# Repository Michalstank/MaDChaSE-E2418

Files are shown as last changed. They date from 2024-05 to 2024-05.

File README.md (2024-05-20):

# Massive Distributed Channel Sounding Equipment 

Dette er repositoriet for bacheloroppgaven "MaDChaSE", i forbindelse med studieretningen elektronikk og sensorsystemer ved [NTNU](https://www.ntnu.no/). Med støtte fra [Nordic Semiconductor](https://www.nordicsemi.com/), ble prosjektet gjennomført for å utvikle et konseptbevis for et system som muliggjør massiv distribuering av noder i stand til å gjennomføre [kanalmåling](https://www.bluetooth.com/specifications/specs/channel-sounding-cr-pr/). Oppgaven ble avgrenset til håndteringen av hundrevis av noder på et nettverk. Dette inkluderer arbeid som: 

- Prototyping av noder.
- Distribuering av fastvare. 
- Verktøy for oppkobling av nye noder til et WiFi-nettverk.
- Kanalmålingsorkestrering og datainnsamling. 

Alle relevante filer inkludert dette databladet finnes under følgende link: https://github.com/Michalstank/MaDChaSE-E2418

## Innholdsfortegnelse
1. [Systemarkitektur](#systemarkitektur)
2. [Requirements](#Requirements)
   1. [Hardware](#hardware)
   2. [Software](#software)
   3. [nRF Libraries](#nrf-libraries) 
4. [Guide for oppsett](#guide-for-oppsett)
    1. [Hardware Oppsett](#Hardware-Oppsett)
    3. [Server Oppsett](#Server-Oppsett)
    4. [Distribusjon av fastvare](#distribusjon-av-fastvare)
    5. [RPI Oppsett](#RPI-Oppsett)
5. [Bash Script](#bash-script)
    1. [Flagg Oversikt](#flagg-oversikt)
    2. [Flagg Kode](#flagg-kode)
  
# Systemarkitektur
Det utviklede systemet baserer seg på noder i form av [nRF52833 Dk.]( https://www.nordicsemi.com/Products/Development-hardware/nRF52833-DK) og [RPI 3B+](https://www.raspberrypi.com/products/raspberry-pi-3-model-b-plus/). nRF-enheten gjennomfører kanalmålinger, mens RPI 3B+ står for nettverkskommunikasjon og distribuerer fastvare nødvendig for målingene. En server brukes som mellomleddet mellom nodene og brukergrensesnittet. Serveren kommuniserer med nodene over et WiFi-nettverk og står for kanalmålingsorkestrering og samhandling. Brukergrensesnittet er i form av en nettside. 


# Requirements
## Hardware 
- En Router / Access Point med Wi-Fi
- nRF52833 Dk.
- Raspberry Pi 3B+ (Eller tilsvarende modell som støtter Rasbian v11.9)
- Micro SD kort
- Power Supply for RPI 
- USB-A til Micro-USB-B kabel

## Software 
- Minst versjon av NodeJS v18.13.0.
- Node pakkene: socketio, express.
- Mulighet for å sjekke IP av enheter koblet til Routeren / Access Point (Eksempelvis logg deg på ruteren du skal bruke for å undersøke dette).
## nRF Libraries
- <zephyr/kernel.h>
- <zephyr/gpio.h>
- <zephyr/uart.h>
- [libnrf_dm.a](https://github.com/nrfconnect/sdk-nrfxlib/blob/main/nrf_dm/lib/nrf52833/hard-float/libnrf_dm.a)

# Guide for oppsett
## Hardware oppsett
RPI 3B+ og nRF52833 Dk. som utgjør nodene, kommuniserer med hverandre ved hjelp av UART-protokollen. For å muliggjøre kommunikasjonen, kobl nRF-en til en av USB-A portene på RPI. For å forsyne noden med strøm kobl RPI til strømforsyning. Dette kreves ikke enda, det gjennomføres underveis RPI oppsettet.

Det ble også utviklet en innkapsling til nodene som kan 3D-printes. De tilhørende filene finnes [her.](https://github.com/Michalstank/MaDChaSE-E2418/tree/48b5f4ba134b89f2b8a7d6ff9e974852505d02e9/Extras)


## Server oppsett

Denne delen har som formål å presentere de nødvendige stegene for å sette opp serveren. 

1. Last ned [Server Files](https://github.com/Michalstank/MaDChaSE-E2418/tree/main/SVR).
2. Utpakk filene og bestem hvilken algoritme du ønsker å bruke (list eller rng.).
3. Start 'Node.js Command Prompt'
4. Start serveren ved å skrive inn følgende kommando:
```bash
node server_file_name.js
```
5. Om det forekommer en feil, dobbelsjekk at alle filene er i samme mappe.
6. For å logge på brukergrensesnittet, finn først IP-en til datamaskinen der serveren skal 'hostes' og legg til dens port på følgende form: IP:PORT. For å nå brukergrensesnittet skriv deretter den sammensatte IP-en og porten inn i nettleseren.
```bash
192.168.10.187:3000 or localhost:3000
```
7. For at nodene skal være i stand til å koble seg opp til serveren din, endr client.py filen. Definer IP'en du tidligere fant på linje 119:
```python
sio.connect('http://IP:PORT', retry = True); example: sio.connect('http://192.168.2.12:3000', retry = True) 
```

## Distribusjon av fastvare

Nodene i prosjektet henter programvaren sin fra et gitt [Github Repo.](https://github.com/Michalstank/MaDChaSE-E2418-Fastvare) Om du har lyst å endre hvilket repo fastvaren lastes ned fra, endr linken i flagg ['-d'](#flagg--d-kode) i bash scriptet til ønsket repo.<br/> HUSK: linken som erstattes skal være til et 'raw' format av filen på github. Dette gir deg muligheten til å teste ut din egen fastvare på nodene. 

## RPI Oppsett

Denne delen forklarer trinnvis hvordan nodene skal settes opp og programmeres. For hver node i systemet gjennomfør følgende oppstartsprosedyre:

1. Last ned filene: [Bash Script](https://github.com/Michalstank/MaDChaSE-E2418/blob/main/RPI/node_system.sh), [Raspberry Pi Imager](https://downloads.raspberrypi.org/imager/imager_latest.exe) og [RPI Image](https://downloads.raspberrypi.com/raspios_oldstable_full_armhf/images/raspios_oldstable_full_armhf-2024-03-12/2024-03-12-raspios-bullseye-armhf-full.img.xz).
3. Flash RPI SD kortet ved bruk av Raspberry Pi Imager, bildet nedenfor viser anbefalt konfigurasjon. (Huske å legge til Wi-Fi login og passord til nettverket du ønsker at nodene skal kobles på):<br />
   

5. Legg inn SD-kortet i RPI og kobl enheten til strøm. Deretter logg på Router / Access Point for å hente dens IP-adresse.
6. Send over bash script-filen ved bruk av:
```bash
scp PATH_TO_BASH_SCRIPT rpi_navn@rpi_ip:/home/rpi_navn/
```
6. Kobl deg opp til noden ved hjelp av SSH-protokollen: <br /> Hint: Dette steget kan unngås dersom du kobler opp din RPI til en skjerm og tastatur. Etter oppkoblingen åpn opp terminalen og følg steg 7.
```bash
shh rpi_navn@rpi_ip 
```
7. Gjør Bash scriptet til en executable:
```bash
chmod u+x bash_script_navn.sh
```
8. Nå er det mulig å kjøre Bash scriptet dersom man er i samme directory som den:
```bash
./bash_script_navn.sh
```
9. Bash scriptet kan nå også konfigureres til å kjøre ved systemstart. Dette gjøres ved å legge dens 'path' til rc.local filen:
```bash
sudo nano /etc/rc.local
```
10. Dersom du har fulgt stegene skal oppsettet ligne på det nedenfor:
```bash
#Kommentar og default kode over...
./home/rpi_navn/bash_script_navn.sh
```

# Bash Script
Nodenes fastvare oppdateres ved hjelp av et Bash script. Det anvendes for å laste ned bibliotekene, filene og verktøyene som brukes på RPI-en.
## Flagg Oversikt

| Flag | Funksjon |
|---|---|
|`-p`  | Installerer nødvendige Python-bibliotek systemet benytter. |
|`-d`  | Laster ned de nye filene for noden: Client.py og Zephyr.hex (Fastvare for nFR). |
|`-f`  | Installer JLink på RPI og lager et eget directory for den. |
|`-j`  | Installerer fastvare til nRF-en ved hejlp av HEX-filer via. JLink. |
|`-r`  | Sletter gammelt directory laget for JLink. |
|`-s`  | Starter klient-delen etter prosessering av tidligere flagg. |

## Flagg Kode
### Flagg '-p' Kode
```bash
	p) 
		#Update RPI system
		sudo apt-get -y update

		sudo apt-get -y upgrade

		#Install needed python packages
		sudo pip install python-socketio

		sudo pip install "python-socketio[client]"

		sudo pip install pyserial
	;;
```
### Flagg '-d' Kode
```bash
#Download new client and hex file
	d)
		#Remove Old Files
		sudo rm client.py
		sudo rm zephyr.hex

		#Download python client code
		wget --no-check-certificate "https://raw.githubusercontent.com/Michalstank/TEST-DOWNLOAD-REPO/main/client.py"

		#Download hexfile code
		wget --no-check-certificate "https://raw.githubusercontent.com/Michalstank/TEST-DOWNLOAD-REPO/main/zephyr.hex"
	;;
```
### Flagg '-f' Kode
```bash
#Flash Using JLink
	f)	
		#Download Expect and Install Expect, Needed For Flashing/Dealing with JLink
		sudo apt-get -y install expect

		#Move To JLink Directory
		cd JLINK_DATA

		#Start Expect and run JLink Flashing Process
		expect <<-EOF
			set timeout -1
			spawn sudo ./JLinkExe
			expect "J-Link>" 	{ send "connect\r" 	}
			expect "Device>"	{ send "nrf52833\r"	}
			expect "TIF>" 		{ send "S\r" 		}
			expect "Speed>"		{ send "\r" 		}
			expect "J-Link>"	{ send "loadfile /home/e2418/zephyr.hex\r"}
			expect "J-Link>"	{ send "r\r"		}
			expect "J-Link>"	{ send "g\r"		}
			expect "J-Link>"	{ send "exit\r"		}
		EOF

		#Return the the previous directory after done with flashing
		cd ..
	;;
```
### Flagg '-j' Kode
```bash
#Install JLink
	j) 
		#Remove Old JLink Folder
		sudo rm -r JLINK_DATA

		#Download JLink Package
		sudo wget --post-data 'accept_license_agreement=accepted&non_emb_ctr=confirmed&submit=Download+software' https://www.segger.com/downloads/jlink/JLink_Linux_arm.tgz

		#Create Unpack Directory
		sudo mkdir JLINK_DATA

		#Unpack JLink into Its New Directory
		sudo tar -xf JLink_Linux_arm.tgz -C ./JLINK_DATA --strip-components=1

		#Delete JLink Package
		sudo rm JLink_Linux_arm.tgz
	;;
```
### Flagg '-r' Kode
```bash
#Remove JLink folder post install
	r)
		sudo rm -r JLINK_DATA
	;;
```
### Flagg '-s' Kode
```bash
#Run the server
	s) 
		python client.py
	;;
```

# Anerkjennelser
- Vi vil rette en spesiell takk til vår eksterne veileder [Carsten Wulff](https://www.ntnu.no/ansatte/carstenw), for teknisk assistanse og verdifulle tilbakemeldinger underveis i prosjektgjennomføringen. Vi setter pris på [eksempelkoden](https://github.com/wulffern/nrfdmiq/tree/main) vi fikk mulighet til å ta i bruk.
- Vi vil også takke vår prosessveileder [Arne Midjo](https://www.ntnu.no/ansatte/arne.midjo) for råd og støtte gjennom hele prosjektet.

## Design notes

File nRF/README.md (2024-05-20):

# Innhold: 
Denne mappen inneholder main.c filen og de tilhørende bibliotekene for nRF52833 Dk. Dette inkluderer: 

- libnrf_dm.a = Nordic Semiconductor sitt bibliotek for Channel Sounding.
- main.c = Hovedkoden for nRF-enhetene.
- nrf_dm.h = Header fil for libnrf_dm.a biblioteket.
- uart_com.h = Bibliotek for UART kommunikasjon.
- zephyr.hex = Hovedfilen som skal lastes opp på nRF-enhetene.

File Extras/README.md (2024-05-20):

# Extras

Dette er en mappe som inneholder andre relevante ting for prosjektet. Dette inkluderer:
- Filene for 3D-printing av innkapslingen.
- Plotting av data
- Rå data fra de gjennomførte testene. 

I den endelige løsingen ble serveren satt opp for å behandle data på en måte som tilrettelegger for videre prosessering ved hjelp av python bibliotek som pandas. Under gruppens tester ble et alternativt format brukt, for å øke lesbarheten.

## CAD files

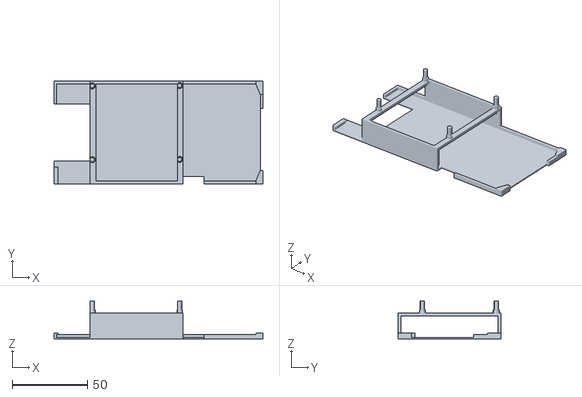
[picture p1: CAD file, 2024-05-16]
Extras/3Dprint/nrf_3d_mode_case.stl
138.7 x 68.1 x 25.0

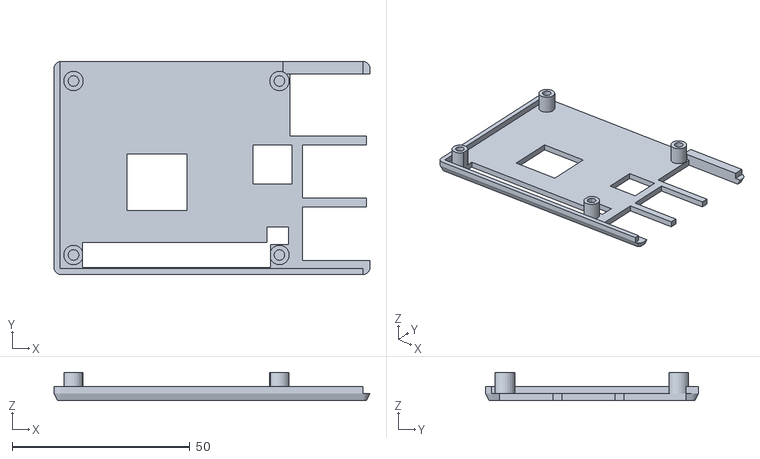
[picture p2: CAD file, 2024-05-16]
Extras/3Dprint/rpi_3d_model_case.stl
89.0 x 60.0 x 8.00

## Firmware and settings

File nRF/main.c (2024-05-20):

/*
	* USE EXTENSION "BETTER COMMENTS by Aaron Bond" FOR BETTER READABILITY
	
	Ref:

	Normal Comment
	//Crossed off Comment (if in multiline comment)
	!RED ERROR LIKE COMMENT
	TODO: TODO ITEM
	* BRIGH COMMENT
	? QUESTION COMMENT ?
*/

#include <zephyr/kernel.h>

#include <zephyr/drivers/gpio.h>
#include <zephyr/drivers/uart.h>

#include <string.h>
#include <stdlib.h>
#include <stdio.h>
#include <stdbool.h>

#include "nrf_dm.h"
#include "uart_com.h"

/*
	Struct used to keep data about the UART Configuration
*/
const struct uart_config uart_cnf = {
	.baudrate = 115200,
	.parity = UART_CFG_PARITY_NONE,
	.stop_bits = UART_CFG_STOP_BITS_1,
	.data_bits = UART_CFG_DATA_BITS_8,
	.flow_ctrl = UART_CFG_FLOW_CTRL_NONE
};

typedef enum {
    INITIATOR,
    REFLECTOR,
    NONE
} NODE_TYPE;

bool node_update_role = false;
bool run_meas = false;

NODE_TYPE node_mode = NONE;

void update_role();

int main(void)
{
	//Check If Ready
	if(!device_is_ready(uart_dev)){
		return 10;
	}

	//Check if Configuration Avaible on the Card
	int err = uart_configure(uart_dev, &uart_cnf);

	//If Error Code Match Return Error Code
	if(err == -ENOSYS){
		return -ENOSYS;
	}

	uart_init();

	// * Main Loop

	while(1){

		//Configures and enables the Recieve for UART
		uart_rx_enable(uart_dev, uart_data, sizeof(char)*uart_buffer_size,0);

		//If 4th character in the buffer is not the end of string execute processing of command
		if(uart_data[3] != '\0'){	
			node_update_role = true;	
			uart_rx_disable(uart_dev);
		}

		//Execute code to update role
		update_role();
		
		/*
			Code to execute when the system is set to Initiator Mode
		*/
		if(node_mode == INITIATOR && run_meas){
			
			uart_reset_raport();

			uint32_t nrf_timeout_us 		= 0.5e6;

			nrf_dm_status_t status = nrf_dm_proc_execute(nrf_timeout_us);

			float uart_dis 					= 0;
			uint32_t uart_dur 				= 0;
			uint8_t hopping_seq[NRF_DM_CHANNEL_MAP_LEN];


			/*
				If distance was measured successfully the system will calculate distances
				The distances will be calculated using both the simplified less accurate nrf_dm_calc
				as well as the high precission algorithm nrf_dm_high_precision_calc
			*/
			if(status == NRF_DM_STATUS_SUCCESS){

				nrf_dm_populate_report(&uart_dm_report);

				nrf_dm_calc(&uart_dm_report);

				uart_dur = nrf_dm_get_duration_us(&uart_dm_config);

				uart_dis = nrf_dm_high_precision_calc(&uart_dm_report);

				nrf_dm_get_hopping_sequence(&uart_dm_config, hopping_seq);
			} else {
				//If Distance Measurement failed set quality to 100
				uart_dm_report.quality = 100;
			}

			//Quality 100 = Failed measurement therefore the system will transmit anything but Quality = 100
			if(uart_dm_report.quality != 100){
				//Translate Measured Data to JSON format and transmit it over UART
				uart_nrf_dm_report_to_json(&uart_dm_report, uart_dis, uart_dur, hopping_seq);
			}

			run_meas = false;

		/*
			Code to execute when the node is set to reflector mode
			Primarly focuses on the configuration of the nrf into reflector mode
		*/
		} else if(node_mode == REFLECTOR && run_meas){

			nrf_dm_status_t status = nrf_dm_configure(&uart_dm_config);

			uint32_t dm_timeout = 1e6;

			status = nrf_dm_proc_execute(dm_timeout);

			run_meas = false;
		}
	}
	return 0;
}

/*
	@brief Code to execute once a command from rpi has been recieved. @brief
	@note Proccesses how to configure the nrf based on the recived command.
*/
void update_role(){
	if(node_update_role){

		nrf_dm_role_t current_role;

		//Read Content of USART Transmmited string and compare if it is one of recognised command
		if(        !strncmp(uart_data,"Init.",4)){
			//Set seed necesary for the distance measurement system
			uart_dm_config.rng_seed 	= 0x44ddaafa;

			//Change Mode of node to initiator and change the configuration of dm config
			node_mode = INITIATOR;

			//Update the distance measurement config
			uart_dm_config 				= NRF_DM_DEFAULT_CONFIG;
			uart_dm_config.role			= NRF_DM_ROLE_INITIATOR;

			current_role 				= NRF_DM_ROLE_INITIATOR;

			//Stop the measurement
			run_meas = false;

			//Check if configuration of dm lib was succesful
			nrf_dm_configure(&uart_dm_config);

		//Same functionality as first if case
		} else if (!strncmp(uart_data,"Refl.",4)){
			uart_dm_config.rng_seed 	= 0x44ddaafa;

			node_mode = REFLECTOR;

			uart_dm_config 				= NRF_DM_DEFAULT_CONFIG;
			uart_dm_config.role			= NRF_DM_ROLE_REFLECTOR;

			current_role 				= NRF_DM_ROLE_REFLECTOR;

			run_meas = false;

			nrf_dm_configure(&uart_dm_config);
		//Same functionality as first if case
		} else if (!strncmp(uart_data,"None.",4)){
			uart_dm_config.rng_seed 	= 0;

			node_mode = NONE;

			uart_dm_config 				= NRF_DM_DEFAULT_CONFIG;
			uart_dm_config.role			= NRF_DM_ROLE_NONE;

			current_role 				= NRF_DM_ROLE_NONE;

			nrf_dm_configure(&uart_dm_config);

			run_meas = false;
		
		//
		} else if (!strncmp(uart_data, "Meas.", 4)){
			run_meas = true;
			current_role = uart_dm_config.role;
			uart_put_string("CMeas Start.");
			//If the command does not match any of the predetermined print "Wrong Comamnd" back to the server
		}else {	
			uart_put_string("Cwrng_cmd.");
		}

		//Double check if the mode has updated successfully.
		//If correct print out confirmation to the server.
		if(uart_dm_config.role == current_role){
			uart_put_string("CConf.");
		} else {
			uart_put_string("Cwrng.");
		}

		node_update_role = false;

		//Reset Input String
		memset(uart_data, '\0' , sizeof(uart_data));
	}
}

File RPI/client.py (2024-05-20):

#Socket.io Library
import socketio

#Random ID Generation
import random

#Serial Communication Libraries
import serial
from time import sleep

#Terminal Access Library
import os

#Node Class Definition, going to hold all important information about the node
class Node:
	node_unique_id 	= 0
	node_network_id = 0
	node_mode 	= 0
	node_data	= 0
	node_max_rand	= 100_000_000

#Creates node_info, main variable used to keep track of node information
node_info = Node()

#Variable to keep track if data is expected to be sent back to the server
node_data_expected = False

#Generate "Unique" ID for this node
node_info.node_unique_id = random.randrange(0, node_info.node_max_rand)

def node_update_role(mode):
	if  (mode == "I" or mode == "i" or mode == "T" or mode == "t" or mode == 2):
		node_info.node_mode = "Init."
	elif(mode == "R" or mode == "r" or mode == 1):
		node_info.node_mode = "Refl."
	elif(mode == "O" or mode == "o" or mode == "N" or mode == "n" or mode == 0):
		node_info.node_mode = "None."

#Init Serial Reading
port = serial.Serial("/dev/ttyACM0" , baudrate = 115200, parity=serial.PARITY_NONE, stopbits = serial.STOPBITS_ONE)

##############################################################
###							   ###
###		     SERVER COMMUNICATION         	   ###
###							   ###
##############################################################

#Connection Init
sio = socketio.Client()

#On Connect
@sio.event
def connect():
	#Inform That Successfully Connected to Server
	print('Connected To Server')

	#Emit Message To The Server, Attaching unique ID for it to register the Node
	sio.emit("SVR_NODE_INIT", node_info.node_unique_id)

#On Disconnect
@sio.event
def disconnect():
	print('Disconnected From Server')

#On RPI_NODE_DATA recive, configure rest of the Node based on the info from the server
@sio.event
def RPI_NODE_DATA(svr_data):
	#Check if this is the node to be updated
	if(svr_data["node_unique_id"] == node_info.node_unique_id):
		print(svr_data)
		#Assign new mode and new id of the node
		node_info.node_network_id = svr_data["node_network_id"]
		node_update_role(svr_data["node_mode"])
		port.write(node_info.node_mode.encode())

#On RPI_NODE_RESET, meaning reset the mode to nothing
@sio.event
def RPI_NODE_RESET(svr_data):
	#Universal Command, ID check Not Needed
	node_info.node_mode = "None"
	global node_data_expected
	node_data_expected = False
	port.write("None.".encode())

#On RPI_ROLE_UPDATE, update the role of a node with matching ID
@sio.event
def RPI_ROLE_UPDATE(svr_data):

	#If ID match update role
	if(node_info.node_network_id == svr_data["node_network_id"]):

		#Update Node Role
		node_update_role(svr_data["node_mode"])

		print(node_info.node_mode)

		#Transmit New Mode Over UART
		port.write(node_info.node_mode.encode())

#On RPI_DATA_REQUEST, check if valid node and transmit data
@sio.event
def RPI_DATA_REQUEST(svr_data):
	if(node_info.node_network_id == svr_data["node_network_id"]):
		print("Data Request")
		#Since data might not be ready, set one of variables to true
		#Then transmit data once its ready and clear the variable
		global node_data_expected
		node_data_expected = True
		port.write("Meas.".encode())

#On RPI_NODE_REFLASH, tell the node to reset itself
@sio.event
def RPI_NODE_REFLASH(svr_data):
	port.write("None.".encode());
	os.system('sudo reboot');

#Connect to the server, IP = TEAM LAPTOP IP 
sio.connect('http://192.168.2.157:3000', retry = True)

first_char = True
header_char = ""
output = []

while True:
	#Read input from port
	var = port.read();

	#Decode to normal character
	char = var.decode('latin');

	#Check and update if it is the first character in the message
	if(first_char == True and (char == "C" or char == "J")):
		header_char = char
		first_char = False

	#Check if char is equal to the header char and that it is not one of the blacklisted chars
	if(  header_char == 'C' and char != "" and char != '\x00' and char != '\n' and char != '\r'):
		#Add character to char array
		output.append(char)

		#Assuems End of Transmit
		if(char == "."):
			#Remove Message Identifier
			output.pop(0)

			#Compress UART data into string
			uart_msg = "".join(output)

			#Print Message to terminal
			print(uart_msg)

			#Reset Output array
			output = []

			#Reset waiting for char
			first_char = True
	elif(header_char == 'J' and char != "" and char != '\x00' and char != '\n' and char != '\r'):
		#Add character to char array
		output.append(char)

		#Assumes end of JSON file
		if(char == "}"):

			#Remove the J character at the start
			output.pop(0)

			#Create json packet by converting character array to string
			json_packet = "".join(output)

			#Print and save json data locally
			print(json_packet)
			node_info.node_data = json_packet

			#Reset Output
			output = []

			#Check is server expects data
			if(node_data_expected == True):

				#Send JSON file to the server
				sio.emit("SVR_DATA_CONTENT", json_packet)

				#Stop Waiting For Data
				node_data_expected = False

				#Reset waiting for char
				first_char = True
sio.wait()
